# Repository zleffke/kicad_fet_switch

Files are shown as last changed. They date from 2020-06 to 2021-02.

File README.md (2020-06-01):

# kicad_fet_switch
High Current, DC, High Side, P-Channel MOSFET Switch.  Based on W6PQL design.

### Credit where its due:
[High Current DC Switch](https://www.w6pql.com/high_current_solid-state_dc_switch.htm) from W6PQL.

This design is the identical circuit, just a kicad implementation and variations on the layout for my own projects.

#### Versions:

high_current_v1 - initial prototype design, fixed resistors, no mounting screw, all SMT.
 - Rev- sent to Osh Park, 20200601

high_current_v2 - Same base design, variable resistors for R1, R5, R6 to set for any range up to ~50V.

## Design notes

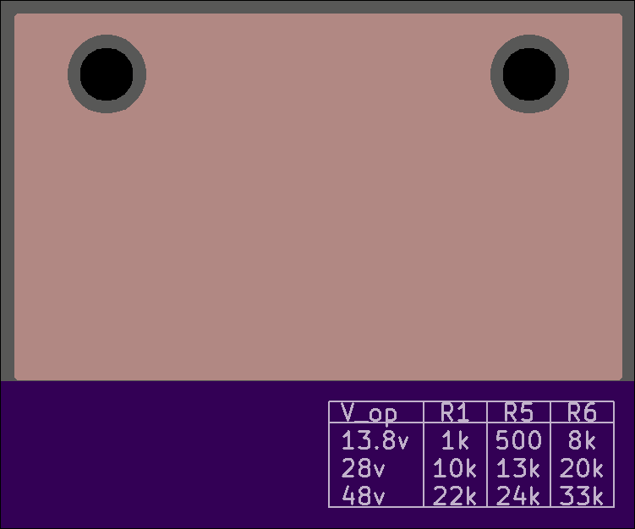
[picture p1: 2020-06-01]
high_current_v2/rev-/osh_park_bottom_view.png

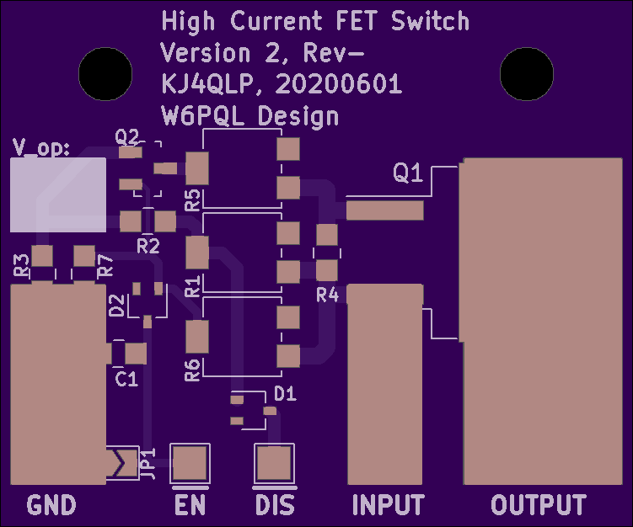
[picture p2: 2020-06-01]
high_current_v2/rev-/osh_park_top_view.png

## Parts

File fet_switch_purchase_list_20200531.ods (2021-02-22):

Supplier | Part # | Description | U/L | Qty | Unit Cost | Total Cost | LINK | Comment | Order Status
Digikey | FQB47P06TM-AM002CT-ND | P-Channel 60V 47A (Tc) 3.75W (Ta), 160W (Tc) Surface Mount D²PAK (TO-263AB) | ea | 10 | $2.14 | $21.42 | LINK (https://www.digikey.com/product-detail/en/on-semiconductor/FQB47P06TM-AM002/FQB47P06TM-AM002CT-ND/3042592) | Q1
Digikey | BAS16LT1GOSCT-ND | Diode Standard 100V 200mA (DC) Surface Mount SOT-23-3 (TO-236) | ea | 100 | $0.04 | $3.74 | LINK (https://www.digikey.com/product-detail/en/on-semiconductor/BAS16LT1G/BAS16LT1GOSCT-ND/917796) | D1, D2
Digikey | BAS16WT1GOSCT-ND | Diode Standard 100V 200mA (DC) Surface Mount SC-70-3 (SOT323) | ea | 100 | $0.04 | $4.46 | LINK (https://www.digikey.com/product-detail/en/on-semiconductor/BAS16WT1G/BAS16WT1GOSCT-ND/917797) | D1, D2
Digikey | MMBTA06LT1GOSCT-ND | Bipolar (BJT) Transistor NPN 80V 500mA 100MHz 225mW Surface Mount SOT-23-3 (TO-236) | ea | 100 | $0.06 | $6.27 | LINK (https://www.digikey.com/product-detail/en/on-semiconductor/MMBTA06LT1G/MMBTA06LT1GOSCT-ND/1139832) | Q2
Digikey | MMBTA56LT1GOSCT-ND | Bipolar (BJT) Transistor PNP 80V 500mA 50MHz 225mW Surface Mount SOT-23-3 (TO-236) | ea | 100 | $0.07 | $6.71 | LINK (https://www.digikey.com/product-detail/en/on-semiconductor/MMBTA56LT1G/MMBTA56LT1GOSCT-ND/1139837)
Digikey | 311-33.0KCRCT-ND | 33 kOhms ±1% 0.125W, 1/8W Chip Resistor 0805 (2012 Metric) Moisture Resistant Thick Film | ea | 100 | $0.02 | $1.63 | LINK (https://www.digikey.com/product-detail/en/yageo/RC0805FR-0733KL/311-33-0KCRCT-ND/730810) | R6, 48V
Digikey | 311-20.0KCRCT-ND | 20 kOhms ±1% 0.125W, 1/8W Chip Resistor 0805 (2012 Metric) Moisture Resistant Thick Film | ea | 100 | $0.02 | $1.63 | LINK (https://www.digikey.com/product-detail/en/yageo/RC0805FR-0720KL/311-20-0KCRCT-ND/730667) | R6, 28V
Digikey | 311-8.06KCRCT-ND | 8.06 kOhms ±1% 0.125W, 1/8W Chip Resistor 0805 (2012 Metric) Moisture Resistant Thick Film | ea | 100 | $0.02 | $1.63 | LINK (https://www.digikey.com/product-detail/en/yageo/RC0805FR-078K06L/311-8-06KCRCT-ND/731092) | R6, 13.8V
Digikey | 311-24.0KCRCT-ND | 24 kOhms ±1% 0.125W, 1/8W Chip Resistor 0805 (2012 Metric) Moisture Resistant Thick Film | ea | 100 | $0.02 | $1.63 | LINK (https://www.digikey.com/product-detail/en/yageo/RC0805FR-0724KL/311-24-0KCRCT-ND/730703) | R5, 48V
Digikey | 311-13.0KCRCT-ND | 13 kOhms ±1% 0.125W, 1/8W Chip Resistor 0805 (2012 Metric) Moisture Resistant Thick Film | ea | 100 | $0.02 | $1.63 | LINK (https://www.digikey.com/product-detail/en/yageo/RC0805FR-0713KL/311-13-0KCRCT-ND/730531) | R5, 28V
Digikey | 311-499CRCT-ND | 499 Ohms ±1% 0.125W, 1/8W Chip Resistor 0805 (2012 Metric) Moisture Resistant Thick Film | ea | 100 | $0.02 | $1.63 | LINK (https://www.digikey.com/product-detail/en/yageo/RC0805FR-07499RL/311-499CRCT-ND/730933) | R5, 13.8V
Digikey | 311-22.0KCRCT-ND | 22 kOhms ±1% 0.125W, 1/8W Chip Resistor 0805 (2012 Metric) Moisture Resistant Thick Film | ea | 100 | $0.02 | $1.63 | LINK (https://www.digikey.com/product-detail/en/yageo/RC0805FR-0722KL/311-22-0KCRCT-ND/730683) | R1, 48V
Digikey | 311-10.0KCRCT-ND | 10 kOhms ±1% 0.125W, 1/8W Chip Resistor 0805 (2012 Metric) Moisture Resistant Thick Film | ea | 100 | $0.02 | $1.63 | LINK (https://www.digikey.com/product-detail/en/yageo/RC0805FR-0710KL/311-10-0KCRCT-ND/730482) | R1, 28V
Digikey | 311-1.00KCRCT-ND | 1 kOhms ±1% 0.125W, 1/8W Chip Resistor 0805 (2012 Metric) Moisture Resistant Thick Film | ea | 100 | $0.02 | $1.63 | LINK (https://www.digikey.com/product-detail/en/yageo/RC0805FR-071KL/311-1-00KCRCT-ND/730391) | R1, 13.8V
Digikey | 311-2.49KCRCT-ND | 2.49 kOhms ±1% 0.125W, 1/8W Chip Resistor 0805 (2012 Metric) Moisture Resistant Thick Film | ea | 100 | $0.02 | $1.63 | LINK (https://www.digikey.com/product-detail/en/yageo/RC0805FR-072K49L/311-2-49KCRCT-ND/730642) | R7
Digikey | 311-2.00KCRCT-ND | 2 kOhms ±1% 0.125W, 1/8W Chip Resistor 0805 (2012 Metric) Moisture Resistant Thick Film | ea | 100 | $0.02 | $1.63 | LINK (https://www.digikey.com/product-detail/en/yageo/RC0805FR-072KL/311-2-00KCRCT-ND/730611) | R3
Digikey | 311-6.04KCRCT-ND | 6.04 kOhms ±1% 0.125W, 1/8W Chip Resistor 0805 (2012 Metric) Moisture Resistant Thick Film | ea | 100 | $0.02 | $1.63 | LINK (https://www.digikey.com/products/en/resistors/chip-resistor-surface-mount/52?k=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) | R2
Digikey | 3314G-503ECT-ND | 50 kOhms 0.25W, 1/4W Gull Wing Surface Mount Trimmer Potentiometer Cermet 1 Turn Top Adjustment | ea | 10 | $1.91 | $19.14 | LINK (https://www.digikey.com/product-detail/en/bourns-inc/3314G-1-503E/3314G-503ECT-ND/86473)
Digikey | 3314G-203ECT-ND | 20 kOhms 0.25W, 1/4W Gull Wing Surface Mount Trimmer Potentiometer Cermet 1 Turn Top Adjustment | ea | 10 | $1.91 | $19.14 | LINK (https://www.digikey.com/product-detail/en/bourns-inc/3314G-1-203E/3314G-203ECT-ND/86467)
Digikey | 3314G-103ECT-ND | 10 kOhms 0.25W, 1/4W Gull Wing Surface Mount Trimmer Potentiometer Cermet 1 Turn Top Adjustment | ea | 10 | $1.91 | $19.14 | LINK (https://www.digikey.com/product-detail/en/bourns-inc/3314G-1-103E/3314G-103ECT-ND/86464)
Digikey | 3314G-502ECT-ND | 5 kOhms 0.25W, 1/4W Gull Wing Surface Mount Trimmer Potentiometer Cermet 1 Turn Top Adjustment | ea | 10 | $1.91 | $19.14 | LINK (https://www.digikey.com/product-detail/en/bourns-inc/3314G-1-502E/3314G-502ECT-ND/86461)
Digikey | DMG3414U-7DICT-ND | N-Channel 20V 4.2A (Ta) 780mW (Ta) Surface Mount SOT-23-3 | ea | 25 | $0.35 | $8.84 | LINK (https://www.digikey.com/product-detail/en/diodes-incorporated/DMG3414U-7/DMG3414U-7DICT-ND/2183251)
Digikey | DMP3056L-7DICT-ND | P-Channel 30V 4.3A (Ta) 1.38W (Ta) Surface Mount SOT-23 | ea | 25 | $0.29 | $7.17 | LINK (https://www.digikey.com/product-detail/en/diodes-incorporated/DMP3056L-7/DMP3056L-7DICT-ND/5126873)
Digikey | IRLML9301TRPBFCT-ND | P-Channel 30V 3.6A (Ta) 1.3W (Ta) Surface Mount Micro3™/SOT-23 | ea | 25 | $0.27 | $6.78 | LINK (https://www.digikey.com/product-detail/en/infineon-technologies/IRLML9301TRPBF/IRLML9301TRPBFCT-ND/2354253)
Digikey | IRLML6344TRPBFCT-ND | N-Channel 30V 5A (Ta) 1.3W (Ta) Surface Mount Micro3™/SOT-23 | ea | 25 | $0.31 | $7.79 | LINK (https://www.digikey.com/product-detail/en/infineon-technologies/IRLML6344TRPBF/IRLML6344TRPBFCT-ND/2538168)
Digikey | S1MFSCT-ND | DIODE GEN PURP 1KV 1A SMA | ea | 25 | $0.17 | $4.14 | LINK (https://www.digikey.com/product-detail/en/on-semiconductor/S1M/S1MFSCT-ND/965721)
 |  |  |  |  | Subtotal | $173.44

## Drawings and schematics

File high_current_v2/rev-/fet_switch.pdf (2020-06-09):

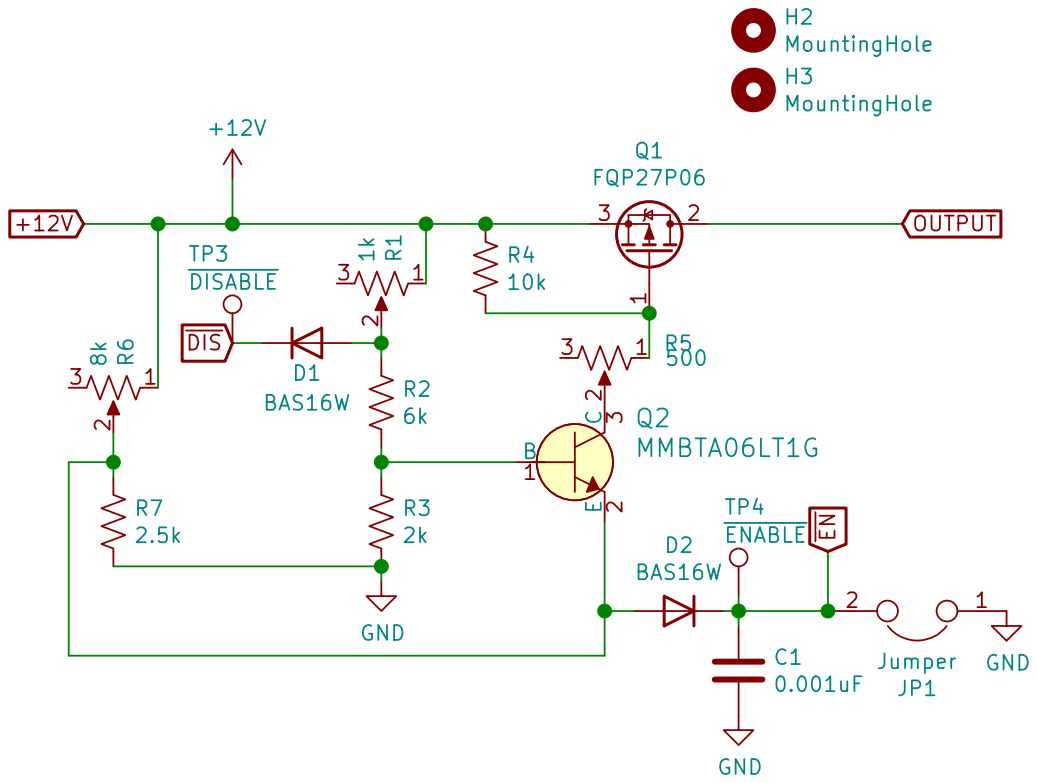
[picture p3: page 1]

creativecommons.org/licenses/by/4.0/ License: CC BY 4.0 Author: Zach Leffke, KJ4QLP

File: fet_switch.sch Sheet: / Amateur Radio Based on W6PQL Design

Id: 1/1 Title: FET Switch

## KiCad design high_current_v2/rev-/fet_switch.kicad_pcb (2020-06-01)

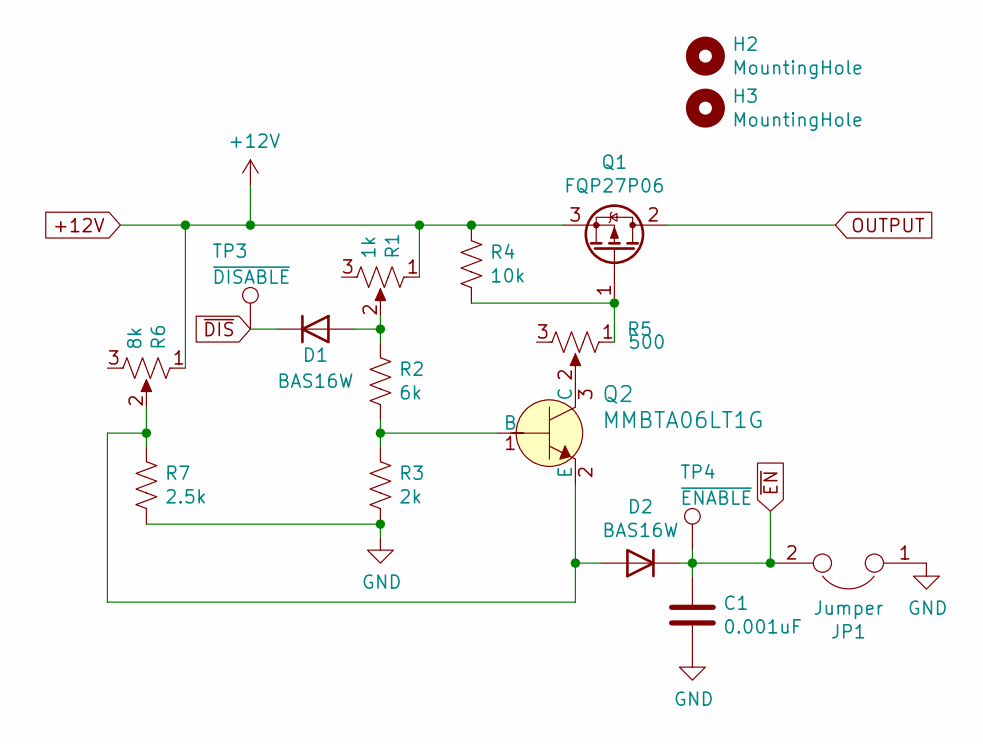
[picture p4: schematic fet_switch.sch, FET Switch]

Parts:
C1: 0.001uF; 0805
D1, D2: BAS16W; SOT-323_SC-70
H2, H3: MountingHole; MountingHole_3.2mm_M3
JP1: Jumper; SolderJumper-2_P1.3mm_Open_TrianglePad1.0x1.5mm
Q1: FQP27P06; TO-263-2
Q2: MMBTA06LT1G; SOT-23-3; MPN MMBTA06LT1G; Digi-Key_PN MMBTA06LT1GOSCT-ND
R1: 1k; Potentiometer_Bourns_3314G_Vertical
R2: 6k; 0805
R3: 2k; 0805
R4: 10k; 0805
R5: 500; Potentiometer_Bourns_3314G_Vertical
R6: 8k; Potentiometer_Bourns_3314G_Vertical
R7: 2.5k; 0805
TP3: ~DISABLE; TestPoint_Pad_2.0x2.0mm
TP4: ~ENABLE; TestPoint_Pad_2.0x2.0mm

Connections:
+12V: Q1.3 (S), R1.1, R4.1, R6.1
GND: C1.2, JP1.1, R3.2, R7.2
unnamed: D1.1 (A), R1.2, R2.1
unnamed: D2.1 (A), Q2.2 (E), R6.2, R7.1
unnamed: Q1.1 (G), R4.2, R5.1
unnamed: Q2.1 (B), R2.2, R3.1
unnamed: Q2.3 (C), R5.2
OUTPUT: Q1.2 (D)
~DIS: D1.3 (K), TP3.1
~EN: C1.1, D2.3 (K), JP1.2, TP4.1

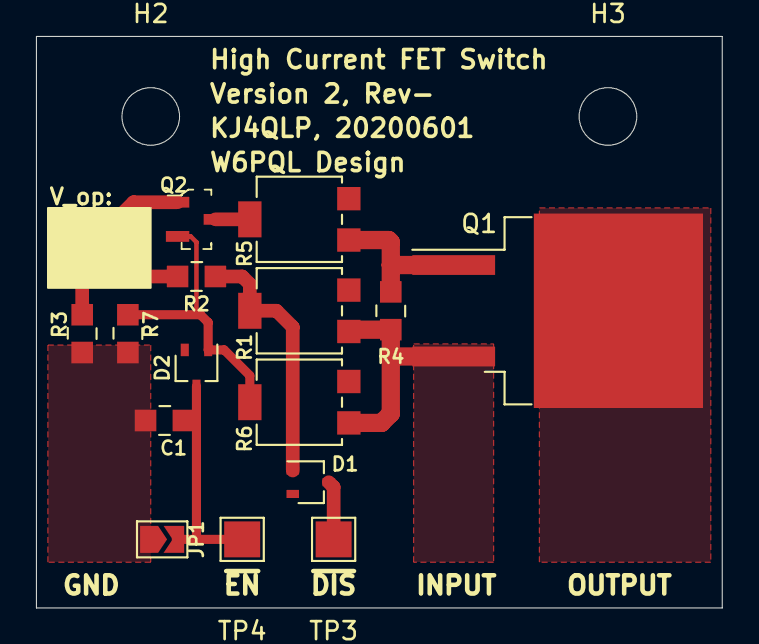
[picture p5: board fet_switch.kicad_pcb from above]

Board: 2 copper layers, 38.1 x 31.8 mm, 17 parts (0 on the bottom side), 9 nets.

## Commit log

2020-06-01 completed design, this commit sent to osh park.
    [fet_switch.kicad_pcb, fet_switch.sch]
2020-06-01 fixed silkscreen...resistor identifiers changed to match W6PQL schematic and table.
    [fet_switch.kicad_pcb, fet_switch.sch]
2020-06-01 version 2, rev-, complete design with trimpots. this commit submitted to osh park.
    [fet_switch.kicad_pcb, fet_switch.sch]
2020-06-09 adding schematic PDFs
2021-02-22 adding purchase list
    [fet_switch_purchase_list_20200531.ods]
